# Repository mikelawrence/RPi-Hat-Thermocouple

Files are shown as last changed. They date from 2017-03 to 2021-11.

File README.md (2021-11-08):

# Raspberry Pi Thermocouple Hat
This is a [Raspberry Pi B+ Hat](https://github.com/raspberrypi/hats) PCB that supports:
* Three MAX31855 Thermocouple Converters for remote temperature sensing
* DS18S20 1-Wire Thermometer for local hat temperature
* DS3231M I2C Real Time Clock for keeping the time when Raspberry is not connected to the internet
* Magnetic Buzzer/Alert (Added with Rev 1.1)

PCB is designed in [KiCad](http://kicad.org) which is a great free EDA toolset and is based on [RPi_Hat_Template](https://github.com/xesscorp/RPi_Hat_Template) by XESS Corp.

## Status
* Rev 1.2 PCB  has been ordered from OSH Park but has NOT been tested yet.
  * Added R7 to prevent the Alert Buzzer from sounding when powered on.
  * Added Analog Power LDO Regulator to help with noise on the MAX31855's temperature readings. Not clear if this will help.
  * You can order parts from Mouser using this [shared BOM](http://www.mouser.com/ProjectManager/ProjectDetail.aspx?AccessID=20F70B46A4).
  * You can order the PCB from OSH Park using this [link](https://oshpark.com/shared_projects/3POTkoNz).
* Rev 1.1 PCB added an Alert Buzzer and has been ordered from OSH Park, assembled, and tested.
  * The Alert Buzzer sounds as soon as the board is powered. Adding a pulldown to base of NUD3124 fixes the problem.
  * There is occasional noise in the temperature readings from the MAX31855's.
* Rev 1.0 PCB has been ordered from OSH Park, assembled, and tested. It is fully operational.

## Board Preview
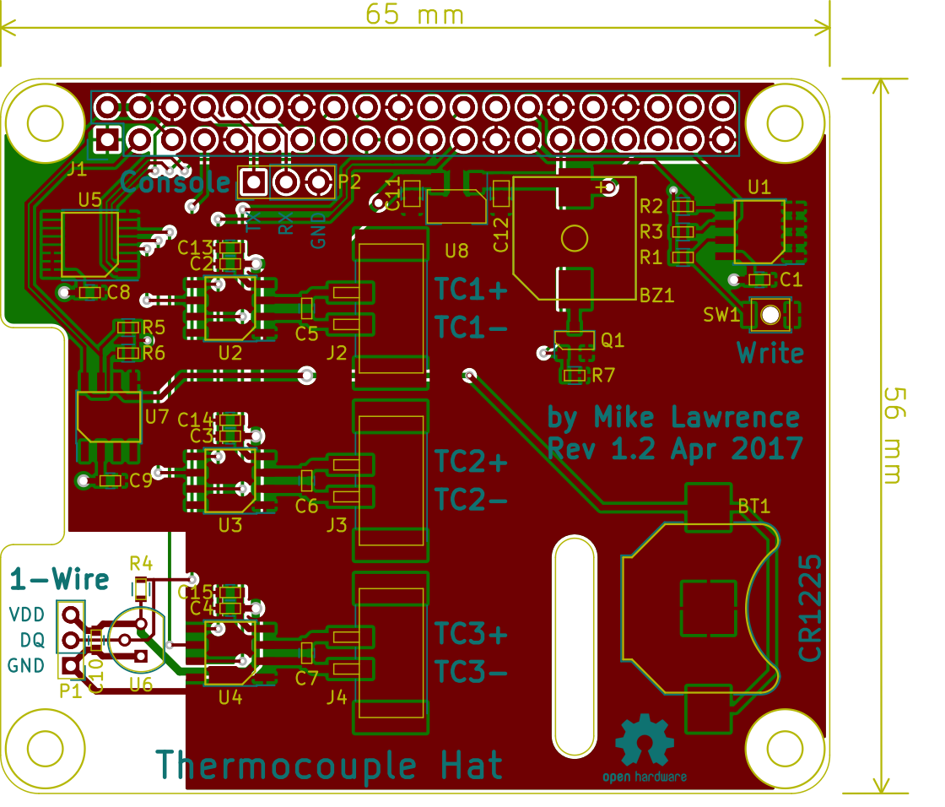
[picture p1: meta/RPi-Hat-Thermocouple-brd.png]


## Raspberry Pi Setup
This setup makes two key assumptions. First you are using Raspbian Jessie. Second Python3 is the target programming environment. Python3 should be installed by default but if it isn't run `sudo apt-get install python3-dev`.

### Configure ID EEPROM
Raspberry Pi Hats require an ID EEPROM with data that uniquely identifies every hat ever made. Start by cloning this repository on your Raspberry Pi, building the EEPROM tools, and make the the `eeprom_settings.eep` file.
```
cd ~/Documents
git clone https://github.com/mikelawrence/RPi-Hat-Thermocouple
cd ~/Documents/RPi-Hat-Thermocouple/eeprom/
make all
./eepmake eeprom_settings.txt eeprom_settings.eep
```
The next command writes the freshly generated and unique `eeprom_settings.eep` file to the EEPROM but you must push and hold the write switch on the hat before executing this command. By default the EEPROM on the hat is write protected. Pushing the write switch allows writes to occur while the switch is pushed.
```
sudo ./eepflash.sh -w -f=eeprom_settings.eep -t=24c32
```
You will see the following if writing to the EEPROM was successful.
```
This will attempt to talk to an eeprom at i2c address 0x50. Make sure there is an eeprom at this address.
This script comes with ABSOLUTELY no warranty. Continue only if you know what you are doing.
Do you wish to continue? (yes/no): yes
Writing...
0+1 records in
0+1 records out
117 bytes (117 B) copied, 2.31931 s, 0.1 kB/s
Done.
```
This is what you will see if there is a problem communicating with the EEPROM.
```
This will attempt to talk to an eeprom at i2c address 0x50. Make sure there is an eeprom at this address.
This script comes with ABSOLUTELY no warranty. Continue only if you know what you are doing.
Do you wish to continue? (yes/no): yes
Writing...
dd: error writing ‘/sys/class/i2c-adapter/i2c-3/3-0050/eeprom’: Connection timed out
0+1 records in
0+0 records out
0 bytes (0 B) copied, 0.0539977 s, 0.0 kB/s
Error doing I/O operation.
```
If you succesfuly wrote the EEPROM there is nothing else left to do here.

### Setup Interfaces
For this Hat you will need to enable the SPI, I2C and 1-Wire interfaces. From the command line type
`sudo raspi-config ` and follow the prompts to install SPI support in the kernel.

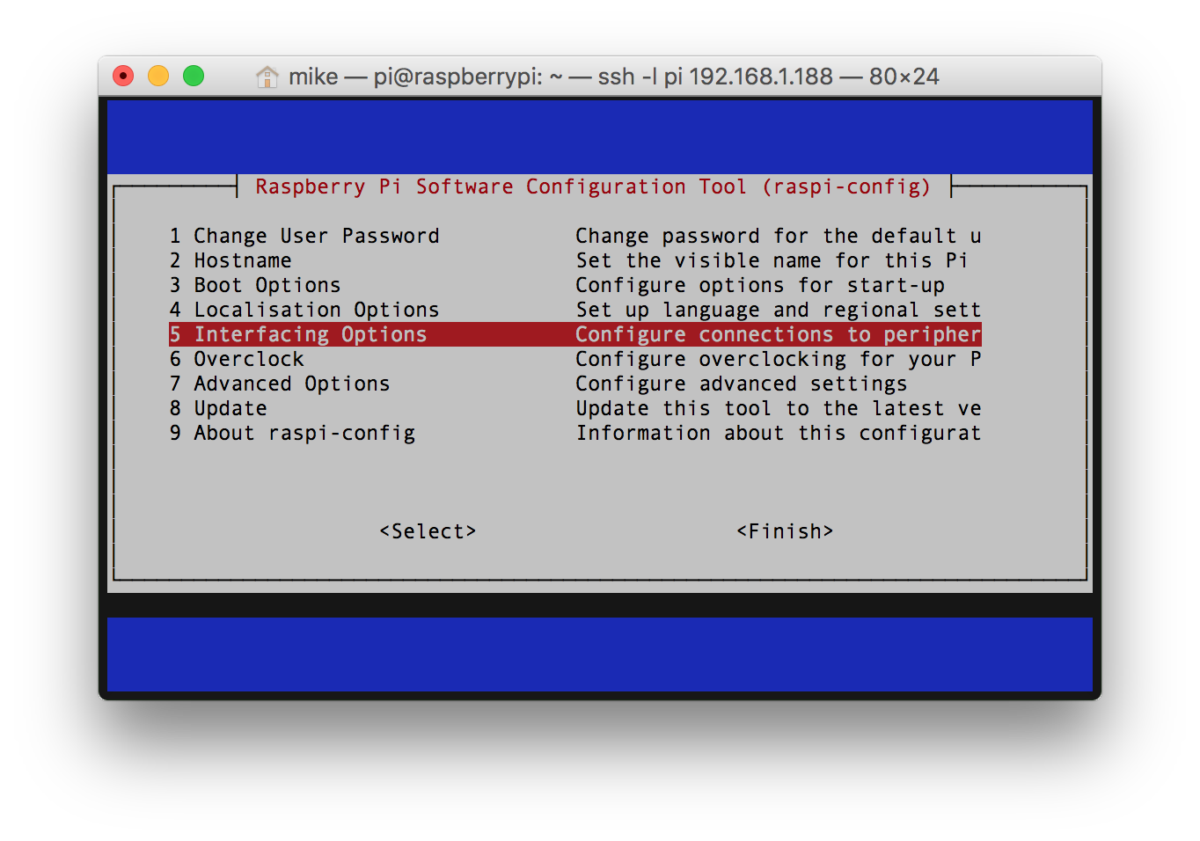
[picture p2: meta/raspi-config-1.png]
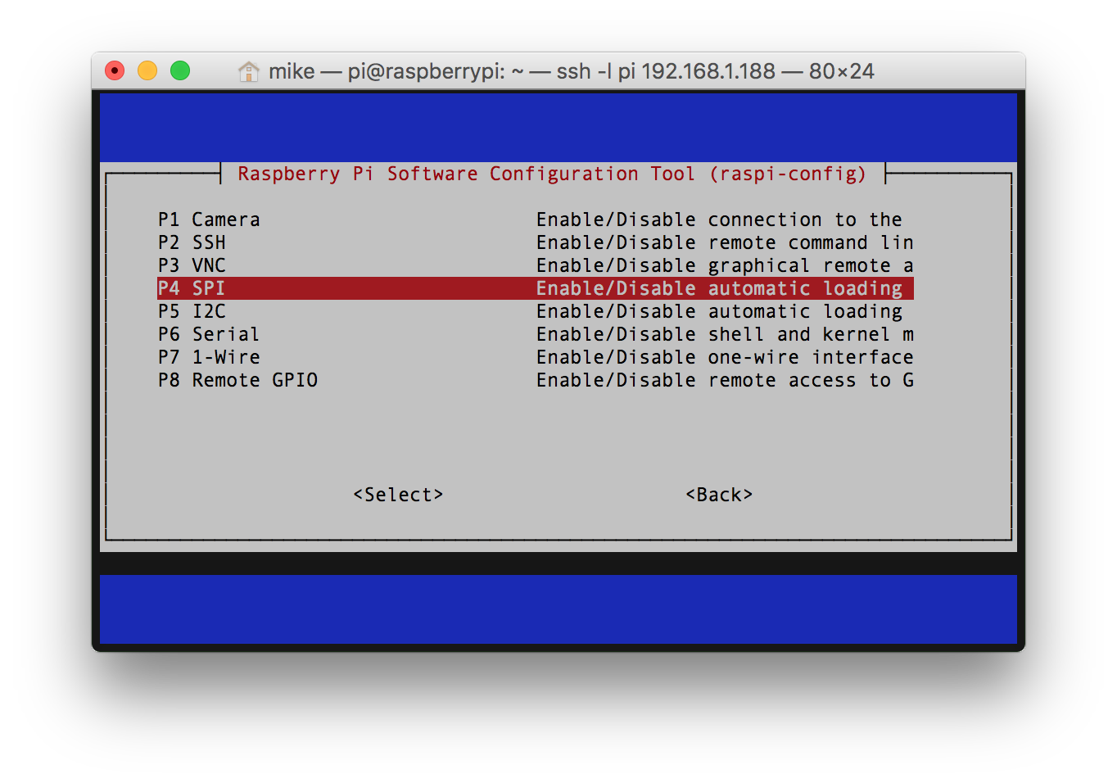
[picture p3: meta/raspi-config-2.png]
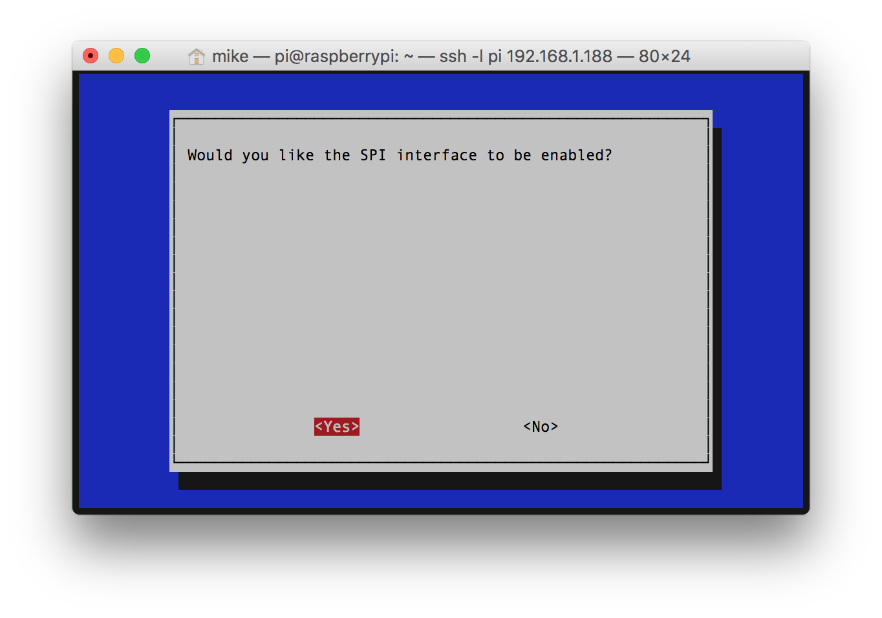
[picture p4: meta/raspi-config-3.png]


Now follow the same actions but enabling the I2C and 1-Wire interfaces.

It's time to reboot your Raspberry Pi with `sudo reboot`.

### Configuring the DS3231 RTC
Now let's see if the RTC is is present on the I2C bus by running `sudo i2cdetect -y 1`. If you get a `command not found` you will need to install it with `sudo apt-get install python-smbus i2c-tools`. Looking at the output of the `i2cdetect` command you will see `68` in a field of `--` when the RTC is detected on the bus.
```
pi@raspberrypi:~ $ sudo i2cdetect -y 1
     0  1  2  3  4  5  6  7  8  9  a  b  c  d  e  f
00:          -- -- -- -- -- -- -- -- -- -- -- -- --
10: -- -- -- -- -- -- -- -- -- -- -- -- -- -- -- --
20: -- -- -- -- -- -- -- -- -- -- -- -- -- -- -- --
30: -- -- -- -- -- -- -- -- -- -- -- -- -- -- -- --
40: -- -- -- -- -- -- -- -- -- -- -- -- -- -- -- --
50: -- -- -- -- -- -- -- -- -- -- -- -- -- -- -- --
60: -- -- -- -- -- -- -- -- 68 -- -- -- -- -- -- --
70: -- -- -- -- -- -- -- --                         
```
Enable kernel support for the DS3231 RTC by adding a device tree overlay by running `sudo nano /boot/config.txt` and adding the following to the end of the file. Don't forget to save the file.
```
# Enable Real Time Clock
dtoverlay=i2c-rtc,ds3231
```
Reboot again. Now when `sudo i2cdetect -y 1` is run we see:
```
pi@raspberrypi:~ $ sudo i2cdetect -y 1
     0  1  2  3  4  5  6  7  8  9  a  b  c  d  e  f
00:          -- -- -- -- -- -- -- -- -- -- -- -- --
10: -- -- -- -- -- -- -- -- -- -- -- -- -- -- -- --
20: -- -- -- -- -- -- -- -- -- -- -- -- -- -- -- --
30: -- -- -- -- -- -- -- -- -- -- -- -- -- -- -- --
40: -- -- -- -- -- -- -- -- -- -- -- -- -- -- -- --
50: -- -- -- -- -- -- -- -- -- -- -- -- -- -- -- --
60: -- -- -- -- -- -- -- -- UU -- -- -- -- -- -- --
70: -- -- -- -- -- -- -- --                         
```
The `UU` at address 68 means the RTC is currently in use by a driver or in other words we have success! Now disable the fake hwclock because it will interfere with our new RTC. Issue the following commands.
```
sudo apt-get -y remove fake-hwclock
sudo update-rc.d -f fake-hwclock remove
```
Next run `sudo nano /lib/udev/hwclock-set` and comment out the following lines. This puts the original clock script back to normal.
```
#if [ -e /run/systemd/system ] ; then
# exit 0
#fi
```
### Setting the time in the RTC
First make sure you have installed the CR1225 battery on the Hat. Next verify the Raspberry Pi has the correct time by typing `date`.
```
pi@raspberrypi:~ $ date
Fri Mar 10 16:52:48 CST 2017
```
If the time is not correct connect the Raspberry Pi to a network via Ethernet or WiFi and allow it synchronize with Internet time servers or set the time manually. Once the time is correct issue this command `sudo hwclock -w`. This will set the RTC time to current system time. The next time the Raspberry Pi is booted it will get it's time from the RTC.

### Using the DS18S20 1-Wire Thermometer
[Here](https://github.com/timofurrer/w1thermsensor) is a nice 1-Wire python library that also supports command line reading of the temperature. If you get a 'command not found' then install it with `sudo apt-get install python3-w1thermsensor`.

Now test the Thermocouple Hat's DS18S20 temperature sensor with `pi@raspberrypi:~ $`.
```
pi@raspberrypi:~ $ w1thermsensor all
Got temperatures of 1 sensors:
  Sensor 1 (0008033f727f) measured temperature: 32.312 celsius
```
### Using the MAX31855 SPI Thermocouple Converters
The Thermocouple Hat design gets around the Raspberry Pi limitation of only two chip enables for the hardware SPI0 interface by adding a 74LVC139A 2to4 Decoder to CEO. The address lines of the 2to4 decoder are connected to GPIO24 and GPIO23 so when SPI0.CE0 is sent low only one of the Thermocouple converters will be selected according to the following logic.

| GPIO23 (Pin 16) | GPIO24 (Pin 18) | Thermocouple |
|:---:|:---:|---|
| 0 | 0 | TC1 |
| 0 | 1 | TC2 |
| 1 | 0 | TC3 |
| 1 | 1 | Invalid |

[Spidev](https://github.com/doceme/py-spidev) is a commonly used Python library for Raspberry Pi SPI programming. This library is most likely already installed but if not install it with `sudo apt-get install python3-spidev`. Assuming you already cloned this repository issue this command `~/Documents/RPi-Hat-Thermocouple/code/test.py` to see the DS18S20 PCB and thermocouple temperatures. Note when I ran the test on my board there was only one connected thermocouple so the other MAX31855K's show as 'No thermocouple connected'.
```
pi@raspberrypi:~ $ ~/Documents/RPi-Hat-Thermocouple/code/test.py
Press Ctrl-C to quit.
Testing alert buzzer...

DS18S20 on PCB: 28.88C / 83.97F
Thermocouple 0: 21.63C / 70.93F
Thermocouple 1: Error - No thermocouple connected
Thermocouple 2: Error - No thermocouple connected
```
# Acknowledgments
[Adafruit](www.adafruit.com) released a guide to [configuring a RTC on a Raspberry Pi](https://cdn-learn.adafruit.com/downloads/pdf/adding-a-real-time-clock-to-raspberry-pi.pdf) that was extremely helpful is setting up the DS3231M RTC. The MAX31855 code is based on an Adafruit [library](https://github.com/adafruit/Adafruit_Python_MAX31855).

Adafruit has breakout boards for the key chips on this Hat here: [RTC](https://www.adafruit.com/products/3013) and [MAX31855](https://www.adafruit.com/products/269). They support the open soruce/hardware community so support them.

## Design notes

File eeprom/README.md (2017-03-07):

These eeprom utilities come from [Raspberry Pi Hats](https://github.com/raspberrypi/hats/).

Utilities to create, flash and dump HAT EEPROM images.

Edit eeprom_setting.txt for your particular board and run through
eepmake tool, then use eepflash tool to write to attached HAT ID EEPROM

Tools available:

 eepmake: Parses EEPROM text file and creates binary .eep file

 eepdump: Dumps a binary .eep file as human readable text (for debug)

 eepflash: Write or read .eep binary image to/from HAT EEPROM

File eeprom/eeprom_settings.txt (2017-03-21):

########################################################################
# EEPROM settings text file
#
# This text file has been modifed for the Raspberry Pi Thermocouple Hat.
#
# Edit this file for your particular board and run through eepmake tool,
# then use eepflash tool to write to attached HAT ID EEPROM
#
# Tools available:
#  eepmake   Parses EEPROM text file and creates binary .eep file
#  eepdump   Dumps a binary .eep file as human readable text (for debug)
#  eepflash  Write or read .eep binary image to/from HAT EEPROM
#
########################################################################

########################################################################
# Vendor info

# 128 bit UUID. If left at zero eepmake tool will auto-generate
# RFC 4122 compliant UUID
product_uuid 00000000-0000-0000-0000-000000000000

# 16 bit product id
product_id 0x0001

# 16 bit product version
product_ver 0x0002

# ASCII vendor string  (max 255 characters)
vendor "Mike Lawrence"

# ASCII product string (max 255 characters)
product "RPi Thermocouple Hat"

########################################################################
# GPIO bank settings, set to nonzero to change from the default.
# NOTE these setting can only be set per BANK, uncommenting any of
# these will force the bank to use the custom setting.

# drive strength, 0=default, 1-8=2,4,6,8,10,12,14,16mA, 9-15=reserved
gpio_drive 0

# 0=default, 1=slew rate limiting, 2=no slew limiting, 3=reserved
gpio_slew 0

# 0=default, 1=hysteresis disabled, 2=hysteresis enabled, 3=reserved
gpio_hysteresis 0

# If board back-powers Pi via 5V GPIO header pins:
# 0 = board does not back-power
# 1 = board back-powers and can supply the Pi with a minimum of 1.3A
# 2 = board back-powers and can supply the Pi with a minimum of 2A
# 3 = reserved
# If back_power=2 then USB high current mode will be automatically
# enabled on the Pi
back_power 0

########################################################################
# GPIO pins, uncomment for GPIOs used on board
# Options for FUNCTION: INPUT, OUTPUT, ALT0-ALT5
# Options for PULL: DEFAULT, UP, DOWN, NONE
# NB GPIO0 and GPIO1 are reserved for ID EEPROM so cannot be set

#         GPIO  FUNCTION  PULL
#         ----  --------  ----
setgpio   2     ALT0      DEFAULT
setgpio   3     ALT0      DEFAULT
#setgpio  4     INPUT     DEFAULT
setgpio   5     OUTPUT    DOWN
#setgpio  6     INPUT     DEFAULT
setgpio   7     OUTPUT    NONE
setgpio   8     OUTPUT    NONE
setgpio   9     ALT0      NONE
setgpio   10    ALT0      NONE
setgpio   11    ALT0      NONE
#setgpio  12    INPUT     DEFAULT
#setgpio  13    INPUT     DEFAULT
#setgpio  14    INPUT     DEFAULT
#setgpio  15    INPUT     DEFAULT
#setgpio  16    INPUT     DEFAULT
#setgpio  17    INPUT     DEFAULT
#setgpio  18    INPUT     DEFAULT
#setgpio  19    INPUT     DEFAULT
#setgpio  20    INPUT     DEFAULT
#setgpio  21    INPUT     DEFAULT
#setgpio  22    INPUT     DEFAULT
setgpio   23    OUTPUT    NONE
setgpio   24    OUTPUT    NONE
#setgpio  25    INPUT     DEFAULT
#setgpio  26    INPUT     DEFAULT
#setgpio  27    INPUT     DEFAULT

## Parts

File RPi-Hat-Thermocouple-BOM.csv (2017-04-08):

Qty | Reference | Value | Part Number | Manufacturer | Footprint | Vendor | Vendor Part Number | Tolerance
3 | J2-J4 | Push Terminal | 1771091 | Phoenix Contact | Connectors_Phoenix:PhoenixContact_PTSM0,5_2-2,5-V_SMD | Mouser | 651-1771091
1 | U1 | AT24CS32 | AT24CS32-SSHM | Atmel | Housings_SOIC:SOIC-8_3.9x4.9mm_Pitch1.27mm | Mouser | 556-AT24CS32-SSHM-T
1 | U6 | DS18S20 | DS18S20 | Maxim Integrated | TO_SOT_Packages_THT:TO-92_Molded_Narrow | Mouser | 700-DS18S20
1 | U7 | DS3231M | DS3231MZ | Maxim Integrated | Housings_SOIC:SOIC-8_3.9x4.9mm_Pitch1.27mm | Mouser | 700-DS3231MZ+
1 | R1 | 1k | ERJ-3EKF1001V | Panasonic | Resistors_SMD:R_0603 | Mouser | 667-ERJ-3EKF1001V | 1%
2 | R2-R3 | 3.9k | ERJ-3EKF3901V | Panasonic | Resistors_SMD:R_0603 | Mouser | 667-ERJ-3EKF3901V | 1%
1 | R4-R7 | 4.7k | ERJ-3EKF4701V | Panasonic | Resistors_SMD:R_0603 | Mouser | 667-ERJ-3EKF4701V | 1%
6 | C5-C7 C13-C15 | 10nF | GRM188R71H103KA01D | Murata Electronics | Capacitors_SMD:C_0603 | Mouser | 81-GRM39X103K50D
7 | C1-C4 C8-C9 C10 | 0.1uF | GRM188R71H104KA93D | Murata Electronics | Capacitors_SMD:C_0603 | Mouser | 81-GRM39X104K50D
2 | C11-C12 | 2.2uF | GRM21BR71C225KA12L | Murata Electronics | Mouser | 81-GRM21BR71C225KA2L
3 | U2-U4 | MAX31855 | MAX31855KASA+ | Maxim Integrated | Housings_SOIC:SOIC-8_3.9x4.9mm_Pitch1.27mm | Mouser | 700-MAX31855KASA+
1 | U5 | 74LVC139 | SN74LVC139APWR | TI | Housings_SSOP:TSSOP-16_4.4x5mm_Pitch0.65mm | Mouser | 595-SN74LVC139APWR
1 | J1 | RPi_GPIO | 2222 | Adafruit | raspberry-ml:Pin_Header_Straight_2x20 | Mouser | 485-2222
1 | SW1 | Write | B3U-1000P | Omron | Buttons_Switches_SMD:SW_SPST_B3U-1000P-B | Mouser | 653-B3U-1000P
1 | BT1 | CR1225 | 3000 | Keystone Electronics | Battery_Holders:Keystone_3000_1x12mm-CoinCell | Mouser | 534-3000
1 | BZ1 | Buzzer | CUI | CMI-9655S-SMT-TR | cui-ml:CMI-9655S-SMT | Mouser | 490-CMI-9655S-SMT-TR
1 | Q1 | NUD3124 | OnSemi | NUD3124LT1G | TO_SOT_Packages_SMD:SOT-23 | Mouser | 863-NUD3124LT1G
1 | U8 | MCP1754ST | MCP1754ST-3302E/MB | Microchip | Mouser | 579-MCP1754ST3302EMB

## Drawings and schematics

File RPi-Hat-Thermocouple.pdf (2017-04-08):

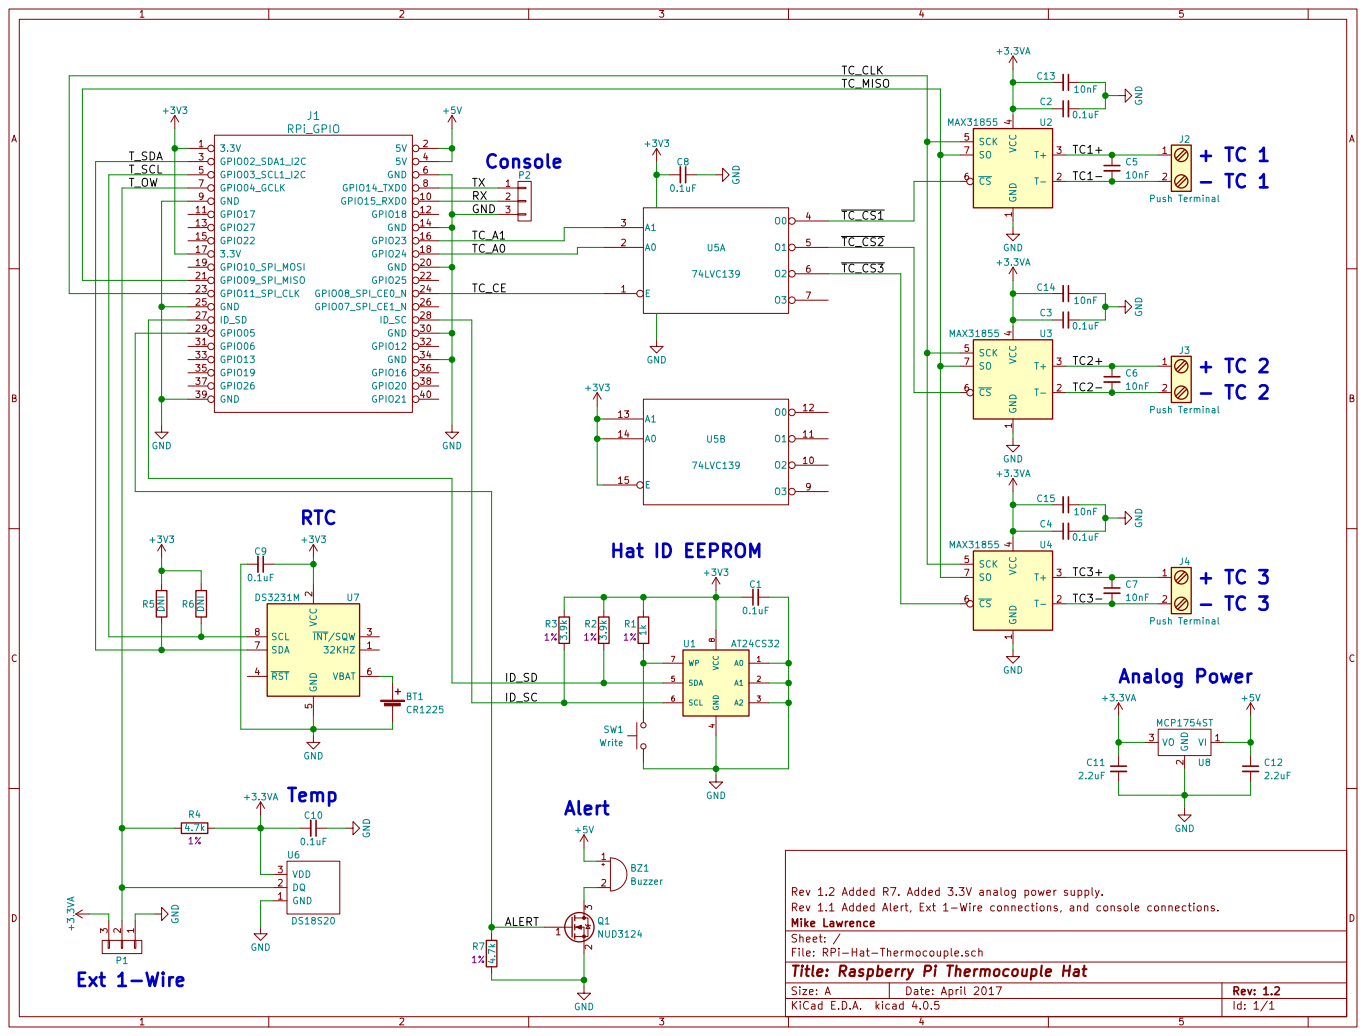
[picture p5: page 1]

TC_MISO

T_SCL
T_OW

4 SDA 5 SCL 6 WP 7 VCC

Rev 1.2 Added R7. Added 3.3V analog power supply.
File: RPi-Hat-Thermocouple.sch Sheet: / Mike Lawrence Rev 1.1 Added Alert, Ext 1-Wire connections, and console connections.

Id: 1/1 Title: Raspberry Pi Thermocouple Hat

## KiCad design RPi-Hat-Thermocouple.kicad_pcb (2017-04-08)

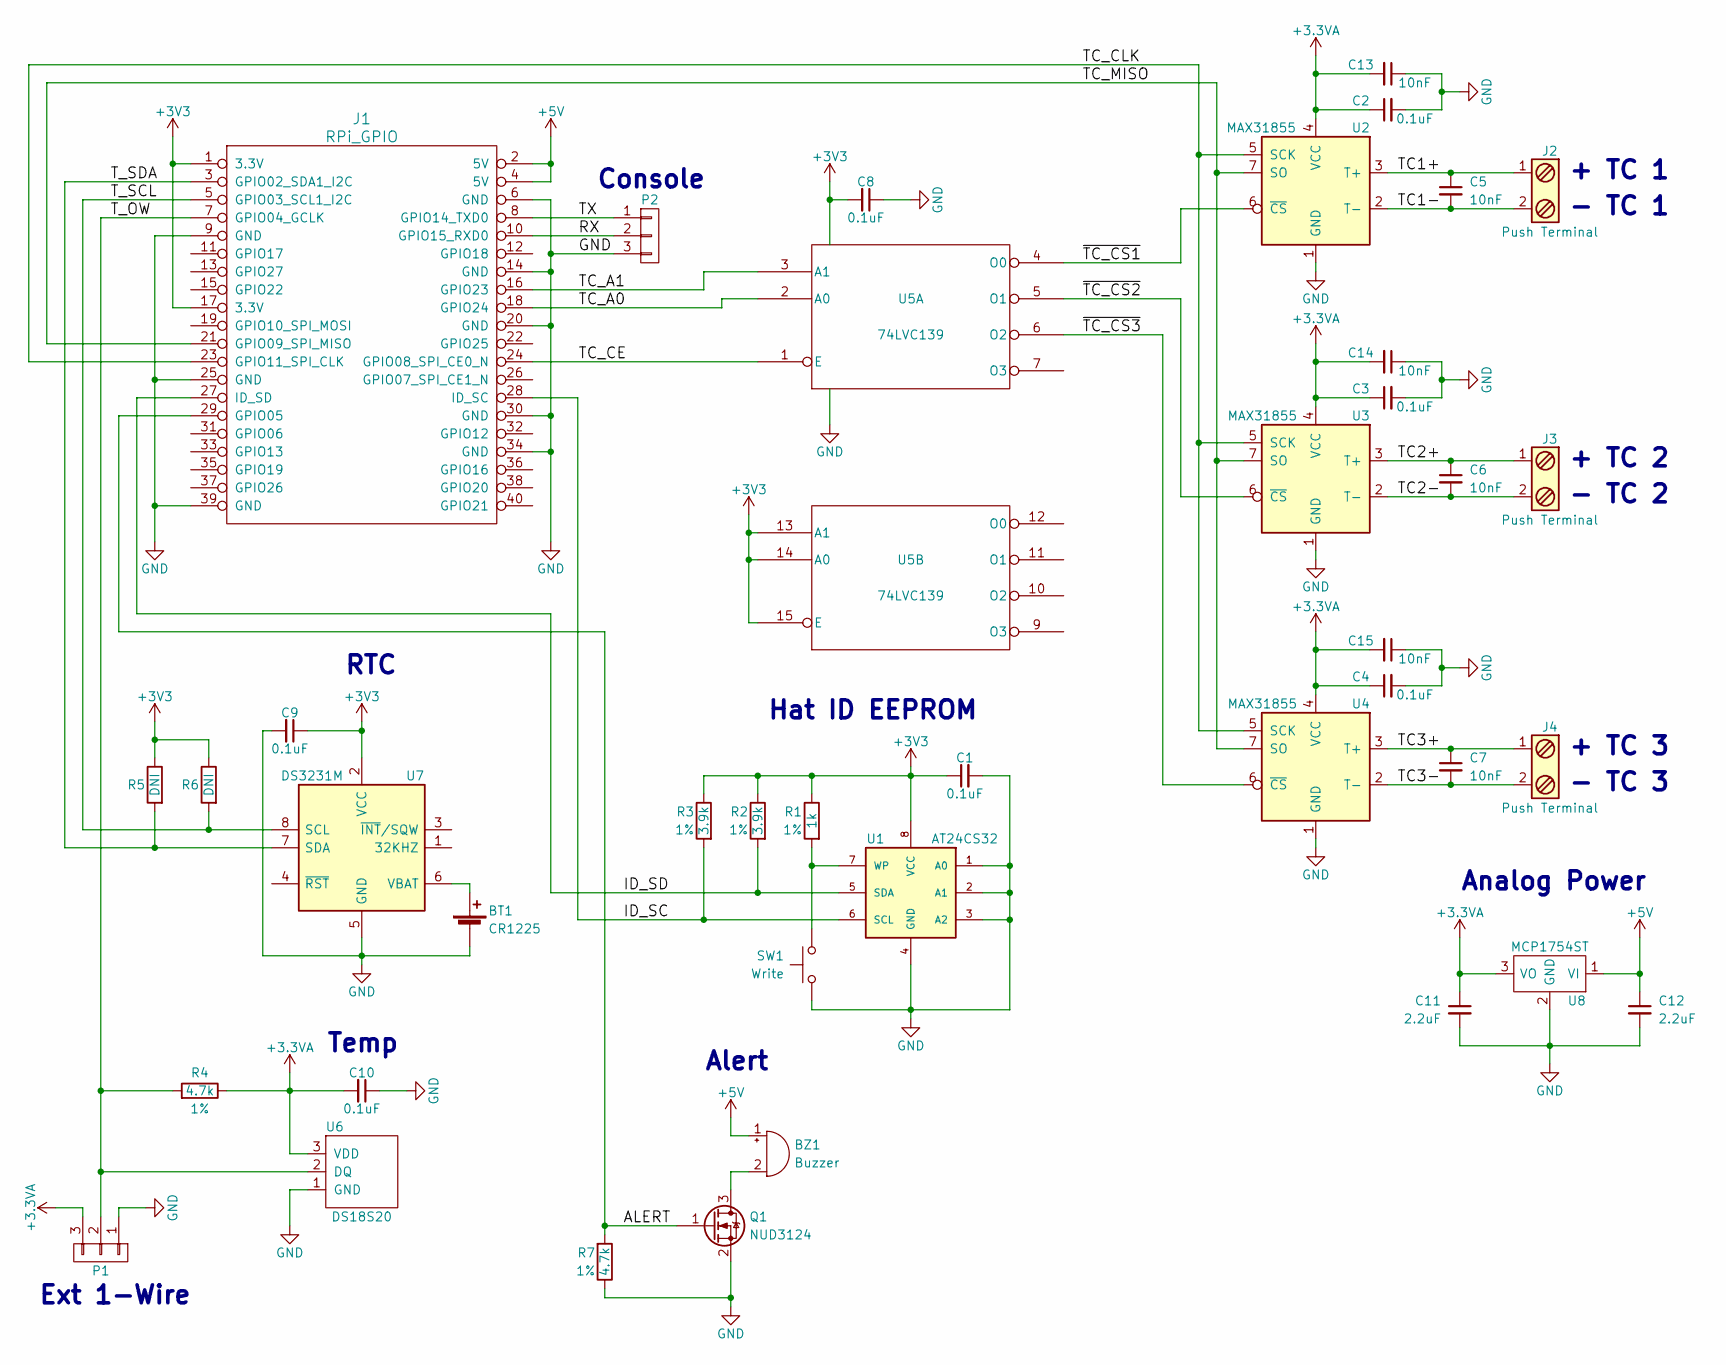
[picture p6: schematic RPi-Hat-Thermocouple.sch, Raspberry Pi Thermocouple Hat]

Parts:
BT1: CR1225; Keystone_3000_1x12mm-CoinCell; Part Number 3000
BZ1: Buzzer; CMI-9655S-SMT; Part Number CMI-9655S-SMT-TR
C1, C2, C3, C4, C8, C9, C10: 0.1uF; C_0603; Part Number GRM188R71H104KA93D
C5, C6, C7, C13, C14, C15: 10nF; C_0603; Part Number GRM188R71H103KA01D
C11, C12: 2.2uF; C_0805; Part Number GRM21BR71C225KA12L
J1: RPi_GPIO; Pin_Header_Straight_2x20; Part Number 2222
J2, J3, J4: Push Terminal; PhoenixContact_PTSM0,5_2-2,5-V_SMD; Part Number 1771091
P1: CONN_01X03; Pin_Header_Straight_1x03_Pitch2.00mm
P2: CONN_01X03; Pin_Header_Straight_1x03_Pitch2.54mm
Q1: NUD3124; SOT-23; Part Number NUD3124LT1G
R1: 1k; R_0603; Tolerance 1%; Part Number ERJ-3EKF1001V
R2, R3: 3.9k; R_0603; Tolerance 1%; Part Number ERJ-3EKF3901V
R4, R7: 4.7k; R_0603; Tolerance 1%; Part Number ERJ-3EKF4701V
R5, R6: DNI; R_0603
SW1: Write; SW_SPST_B3U-1000P-B; Part Number B3U-1000P
U1: AT24CS32; SOIC-8_3.9x4.9mm_Pitch1.27mm; Part Number AT24CS32-SSHM
U2, U3, U4: MAX31855; SOIC-8_3.9x4.9mm_Pitch1.27mm; Part Number MAX31855KASA+
U5: 74LVC139; TSSOP-16_4.4x5mm_Pitch0.65mm; Part Number SN74LVC139APWR
U6: DS18S20; TO-92_Molded_Narrow; Part Number DS18S20
U7: DS3231M; SOIC-8_3.9x4.9mm_Pitch1.27mm; Part Number DS3231MZ
U8: MCP1754ST; SOT89-3_Housing; Part Number MCP1754ST-3302E/MB

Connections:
+3.3VA: C2.1, C3.1, C4.1, C10.2, C11.1, C13.2, C14.2, C15.2, P1.3, R4.1, U2.4 (VCC), U3.4 (VCC), U4.4 (VCC), U6.3 (VDD), U8.3 (VO)
+3V3: C1.1, C8.2, C9.1, J1.1 (3.3V), J1.17 (3.3V), R1.1, R2.1, R3.1, R5.1, R6.1, U1.8 (VCC), U5.13 (A1), U5.14 (A0), U5.15 (E), U5.16 (VCC), U7.2 (VCC)
+5V: BZ1.1 (-), C12.1, J1.2 (5V), J1.4 (5V), U8.1 (VI)
/ALERT: J1.29 (GPIO05), Q1.1 (G), R7.2
/ID_SC: J1.28 (ID_SC), R3.2, U1.6 (SCL)
/ID_SD: J1.27 (ID_SD), R2.2, U1.5 (SDA)
/RX: J1.10 (GPIO15_RXD0), P2.2
/TC1+: C5.1, J2.1, U2.3 (T+)
/TC1-: C5.2, J2.2, U2.2 (T-)
/TC2+: C6.1, J3.1, U3.3 (T+)
/TC2-: C6.2, J3.2, U3.2 (T-)
/TC3+: C7.1, J4.1, U4.3 (T+)
/TC3-: C7.2, J4.2, U4.2 (T-)
/TC_A0: J1.18 (GPIO24), U5.2 (A0)
/TC_A1: J1.16 (GPIO23), U5.3 (A1)
/TC_CE: J1.24 (GPIO08_SPI_CE0_N), U5.1 (E)
/TC_CLK: J1.23 (GPIO11_SPI_CLK), U2.5 (SCK), U3.5 (SCK), U4.5 (SCK)
/TC_MISO: J1.21 (GPIO09_SPI_MISO), U2.7 (SO), U3.7 (SO), U4.7 (SO)
/TX: J1.8 (GPIO14_TXD0), P2.1
/T_OW: J1.7 (GPIO04_GCLK), P1.2, R4.2, U6.2 (DQ)
/T_SCL: J1.5 (GPIO03_SCL1_I2C), R6.2, U7.8 (SCL)
/T_SDA: J1.3 (GPIO02_SDA1_I2C), R5.2, U7.7 (SDA)
/~TC_CS1~: U2.6 (~CS~), U5.4 (O0)
/~TC_CS2~: U3.6 (~CS~), U5.5 (O1)
/~TC_CS3~: U4.6 (~CS~), U5.6 (O2)
GND: BT1.2 (-), C1.2, C2.2, C3.2, C4.2, C8.1, C9.2, C10.1, C11.2, C12.2, C13.1, C14.1, C15.1, J1.6 (GND), J1.9 (GND), J1.14 (GND), J1.20 (GND), J1.25 (GND), J1.30 (GND), J1.34 (GND), J1.39 (GND), P1.1, P2.3, Q1.2 (S), R7.1, SW1.2, U1.1 (A0), U1.2 (A1), U1.3 (A2), U1.4 (GND), U2.1 (GND), U3.1 (GND), U4.1 (GND), U5.8 (GND), U6.1 (GND), U7.5 (GND), U8.2 (GND)
unnamed: BT1.1 (+), U7.6 (VBAT)
unnamed: BZ1.2 (+), Q1.3 (D)
unnamed: R1.2, SW1.1, U1.7 (WP)

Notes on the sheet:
+ TC 1
- TC 1
Hat ID EEPROM
RTC
Temp
Alert
Ext 1-Wire
Console
Analog Power
+ TC 3
- TC 3
+ TC 2
- TC 2

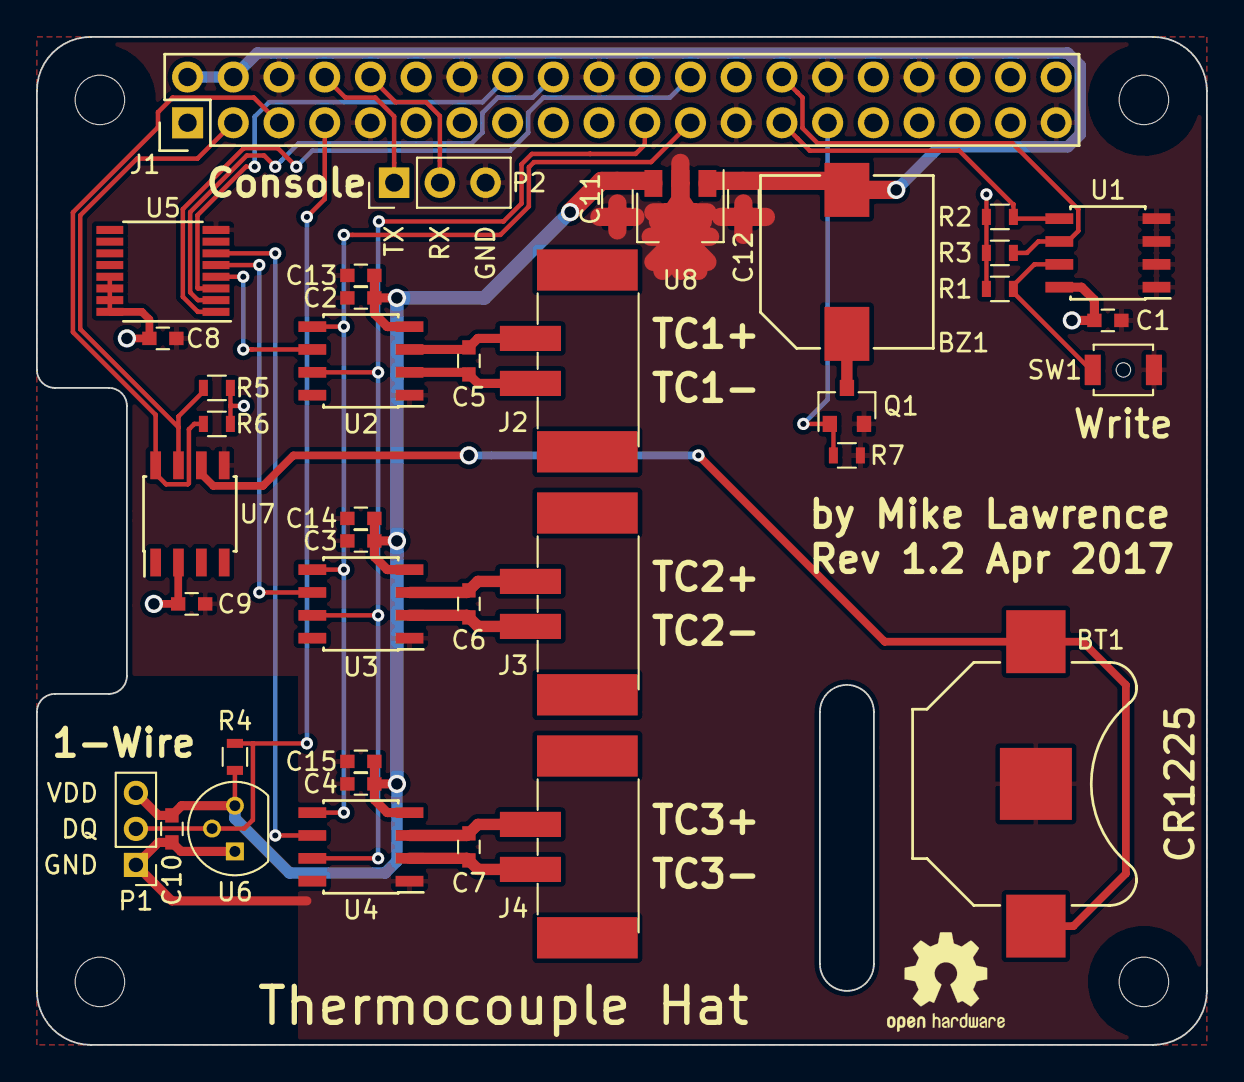
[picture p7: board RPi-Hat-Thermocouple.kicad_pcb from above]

Board: 2 copper layers, 65.0 x 56.0 mm, 40 parts (0 on the bottom side), 29 nets.

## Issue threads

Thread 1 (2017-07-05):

Panasonic Thick Film Resistors

fireballmatt, 2017-07-05:
It looks like both Mouser and DigiKey have run out of stock on some of the 3EKF series SMD TFR's (namely 1001V and 4701V) with something like 30-40 weeks lead time on restock.

Panasonic has released the new PB3B series of the 1001V and 4701V's. Not sure if they are intended as replacements or not.

Are these drop in replacements?

- [ERJ-PV3B1001V](http://www.mouser.com/ProductDetail/Panasonic/ERJ-PB3B1001V/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)
- [ERJ-PV3B4701V](http://www.mouser.com/ProductDetail/Panasonic/ERJ-PB3B4701V/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)

mikelawrence, 2017-07-05:
The resistors you asked about will work fine but they are the rather expensive 0.1% tolerance. Honestly any 0603 resistor will work fine for this design including 5% tolerance.

This one from Yageo will work fine [RC0603FR-074K7L](http://www.mouser.com/ProductDetail/Yageo/RC0603FR-074K7L/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) and is cheaper.

fireballmatt, 2017-07-05:
Thanks Mike!

Closed 2017-07-05.

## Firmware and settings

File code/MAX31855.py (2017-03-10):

# Copyright (c) 2014 Adafruit Industries
# Author: Tony DiCola
# Copyright (c) 2017 Mike Lawrence
#
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
import RPi.GPIO as GPIO
import spidev as SPI

class MAX31855(object):
    ''' Class to represent the MAX31855 thermocouples on the RPi Thermocouple Hat.
    '''

    A0 = 24     # Pin 18 is GPIO24 on later Pi's
    A1 = 23     # Pin 16 is GPIO23 on later Pi's
    PORT = 0    # Thermocouple Hat uses SPI0
    DEVICE = 0  # Thermocouple Hat uses CE0

    def __init__(self):
        ''' Initialize hardware SPI interface to MAX31855 devices
        '''
        self._logger = logging.getLogger('MAX31855')
        self._spi = SPI.SpiDev()
        self._spi.open(MAX31855.PORT, MAX31855.DEVICE)
        self._spi.max_speed_hz=(500000)
        self._spi.mode=(0)   # CPOL=0, CPHA=0
        # turn GPIO address lines into outputs and set to default
        GPIO.setmode(GPIO.BCM)
        GPIO.setup(MAX31855.A0, GPIO.OUT)
        GPIO.setup(MAX31855.A1, GPIO.OUT)
    def readInternalC(self, n=0):
        ''' Return sensor n's internal temperature value in degrees celsius.
        '''
        v = self._read32(n)
        # Ignore bottom 4 bits of thermocouple data.
        v >>= 4
        # Grab bottom 11 bits as internal temperature data.
        internal = v & 0x7FF
        if v & 0x800:
            # Negative value, take 2's compliment. Compute this with subtraction
            # because python is a little odd about handling signed/unsigned.
            internal -= 4096
        # Scale by 0.0625 degrees C per bit and return value.
        return internal * 0.0625

    def readTempC(self, n=0):
        ''' Return the thermocouple temperature value in degrees celsius.
        '''
        v = self._read32(n)
        # Check for error reading value.
        if v & 0x7:
            return float('NaN')
        # Check if signed bit is set.
        if v & 0x80000000:
            # Negative value, take 2's compliment. Compute this with subtraction
            # because python is a little odd about handling signed/unsigned.
            v >>= 18
            v -= 16384
        else:
            # Positive value, just shift the bits to get the value.
            v >>= 18
        # Scale by 0.25 degrees C per bit and return value.
        return v * 0.25

    def readState(self, n=0):
        ''' Return dictionary containing fault codes and hardware problems
        '''
        v = self._read32(n)
        return {
            'openCircuit': (v & (1 << 0)) > 0,
            'shortGND': (v & (1 << 1)) > 0,
            'shortVCC': (v & (1 << 2)) > 0,
            'fault': (v & (1 << 16)) > 0
        }

    def readLinearizedTempC(self, n=0):
        '''Return the NIST-linearized thermocouple temperature value in degrees celsius.
        See https://learn.adafruit.com/calibrating-sensors/maxim-31855-linearization for more info.
        '''
        v = self.readTempC(n)
        if v == float('NaN'):
            return float('NaN')
        # MAX31855 thermocouple voltage reading in mV
        thermocoupleVoltage = (v - self.readInternalC(n)) * 0.041276
        # MAX31855 cold junction voltage reading in mV
        coldJunctionTemperature = self.readInternalC(n)
        coldJunctionVoltage = (-0.176004136860E-01 +
            0.389212049750E-01  * coldJunctionTemperature +
            0.185587700320E-04  * math.pow(coldJunctionTemperature, 2.0) +
            -0.994575928740E-07 * math.pow(coldJunctionTemperature, 3.0) +
            0.318409457190E-09  * math.pow(coldJunctionTemperature, 4.0) +
            -0.560728448890E-12 * math.pow(coldJunctionTemperature, 5.0) +
            0.560750590590E-15  * math.pow(coldJunctionTemperature, 6.0) +
            -0.320207200030E-18 * math.pow(coldJunctionTemperature, 7.0) +
            0.971511471520E-22  * math.pow(coldJunctionTemperature, 8.0) +
            -0.121047212750E-25 * math.pow(coldJunctionTemperature, 9.0) +
            0.118597600000E+00  * math.exp(-0.118343200000E-03 * math.pow((coldJunctionTemperature-0.126968600000E+03), 2.0)))
        # cold junction voltage + thermocouple voltage
        voltageSum = thermocoupleVoltage + coldJunctionVoltage
        # calculate corrected temperature reading based on coefficients for 3 different ranges
        # float b0, b1, b2, b3, b4, b5, b6, b7, b8, b9, b10;
        if thermocoupleVoltage < 0:
            b0 = 0.0000000E+00
            b1 = 2.5173462E+01
            b2 = -1.1662878E+00
            b3 = -1.0833638E+00
            b4 = -8.9773540E-01
            b5 = -3.7342377E-01
            b6 = -8.6632643E-02
            b7 = -1.0450598E-02
            b8 = -5.1920577E-04
            b9 = 0.0000000E+00
        elif thermocoupleVoltage < 20.644:
            b0 = 0.000000E+00
            b1 = 2.508355E+01
            b2 = 7.860106E-02
            b3 = -2.503131E-01
            b4 = 8.315270E-02
            b5 = -1.228034E-02
            b6 = 9.804036E-04
            b7 = -4.413030E-05
            b8 = 1.057734E-06
            b9 = -1.052755E-08
        elif thermocoupleVoltage < 54.886:
            b0 = -1.318058E+02
            b1 = 4.830222E+01
            b2 = -1.646031E+00
            b3 = 5.464731E-02
            b4 = -9.650715E-04
            b5 = 8.802193E-06
            b6 = -3.110810E-08
            b7 = 0.000000E+00
            b8 = 0.000000E+00
            b9 = 0.000000E+00
        else:
            # TODO: handle error - out of range
            return 0
        return (b0 +
            b1 * voltageSum +
            b2 * pow(voltageSum, 2.0) +
            b3 * pow(voltageSum, 3.0) +
            b4 * pow(voltageSum, 4.0) +
            b5 * pow(voltageSum, 5.0) +
            b6 * pow(voltageSum, 6.0) +
            b7 * pow(voltageSum, 7.0) +
            b8 * pow(voltageSum, 8.0) +
            b9 * pow(voltageSum, 9.0))

    def _read32(self, n=0):
        if n == 0:
          # select thermocouple 1
          GPIO.output(MAX31855.A0, GPIO.LOW)
          GPIO.output(MAX31855.A1, GPIO.LOW)
        elif n == 1:
          # select thermocouple 2
          GPIO.output(MAX31855.A0, GPIO.HIGH)
          GPIO.output(MAX31855.A1, GPIO.LOW)
        elif n == 2:
          # select thermocouple 3
          GPIO.output(MAX31855.A0, GPIO.LOW)
          GPIO.output(MAX31855.A1, GPIO.HIGH)
        else:
          # invalid thermocouple
          raise RuntimeError('Read from non-existant thermocouple! Range is 0-2.')
        # Read 32 bits from the SPI bus.
        raw = self._spi.readbytes(4)
        if raw is None or len(raw) != 4:
            raise RuntimeError('Did not read expected number of bytes from device!')
        value = raw[0] << 24 | raw[1] << 16 | raw[2] << 8 | raw[3]
        self._logger.debug('Raw value: 0x{0:08X}'.format(value & 0xFFFFFFFF))
        return value

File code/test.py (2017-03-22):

#!/usr/bin/python3
# Copyright (c) 2017 Mike Lawrence
#
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
# Can enable debug output by uncommenting:
#import logging
#logging.basicConfig(level=logging.DEBUG)

import time

from w1thermsensor import W1ThermSensor
from w1thermsensor import NoSensorFoundError
import RPi.GPIO as GPIO
import MAX31855 as MAX31855

# DS18S20 sensor on PCB
try:
  boardSensor = W1ThermSensor()
except NoSensorFoundError:
  boardSensor = None
  print('DS18S20 Sensor not found!')

# just creating the object will open the correct port and address lines
remoteSensor = MAX31855.MAX31855()

# turn alert signal into an output
ALERT = 5
GPIO.setmode(GPIO.BCM)
GPIO.setup(ALERT, GPIO.OUT)
GPIO.output(ALERT, GPIO.LOW)

# Define a function to convert celsius to fahrenheit.
def c_to_f(c):
  return c * 9.0 / 5.0 + 32.0

# Loop printing measurements every second.
try:
  print('Press Ctrl-C to quit.')
  print("Testing alert buzzer...")
  GPIO.output(ALERT, GPIO.HIGH)
  time.sleep(1)
  GPIO.output(ALERT, GPIO.LOW)
  while True:
    print()
    if boardSensor != None:
      try:
        temp = boardSensor.get_temperature()
        print('DS18S20 on PCB: {0:0.2F}C / {1:0.2F}F'.format(temp, c_to_f(temp)))
      except KeyboardInterrupt:
        break
    for n in range(0,3):
      tempState = remoteSensor.readState(n)
      temp = remoteSensor.readLinearizedTempC(n)
      if tempState['fault']:
        # there is a fault in the reading
        if tempState['openCircuit']:
          error = 'No thermocouple connected'
        elif tempState['shortGND']:
          error = 'Thermocouple shorted to ground'
        elif tempState['shortVCC']:
          error = 'Thermocouple shorted to VCC';
        print('Thermocouple {0:d}: Error - {1}'.format(n, error))
      else:
        print('Thermocouple {0:d}: {1:0.2F}C / {2:0.2F}F'.format(n, temp, c_to_f(temp)))

    time.sleep(1.0)

finally:
  # release GPIO stuff
  GPIO.cleanup()

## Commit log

2017-03-02 Added BOM section to readme file.
2017-03-03 Cleanup Fab layers. Add board preview.
    [RPi-Hat-Thermocouple.kicad_pcb]
2017-03-10 Fixed a couple of mistakes in the README
2017-03-10 Added thermocouple error handling
    [MAX31855.py, test.py]
2017-03-12 Added Alert Buzzer.
    Rev 1.1 will be released soon.
    [RPi-Hat-Thermocouple-BOM.csv, RPi-Hat-Thermocouple.kicad_pcb, RPi-Hat-Thermocouple.sch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]
2017-03-22 Add R7
    R7 prevents alert from going off until software
    [RPi-Hat-Thermocouple-BOM.csv, RPi-Hat-Thermocouple.kicad_pcb, RPi-Hat-Thermocouple.sch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]
2017-04-08 Added Analog Power LDO regulator
    [RPi-Hat-Thermocouple-BOM.csv, RPi-Hat-Thermocouple.kicad_pcb, RPi-Hat-Thermocouple.sch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]
2021-11-08 Update Kicad link.
